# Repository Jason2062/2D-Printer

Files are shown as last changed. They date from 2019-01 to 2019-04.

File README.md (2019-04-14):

# 2D-Printer
This project is a realtime writing machine, which enable user to write information remotely. This design controls the movement of the pen on the x and y axes through two stepping motors and the up and down movement of the pen through a servo motor. The [Wiki page](https://github.com/Jason2062/2D-Printer/wiki) details how to recreate the machine.<br>

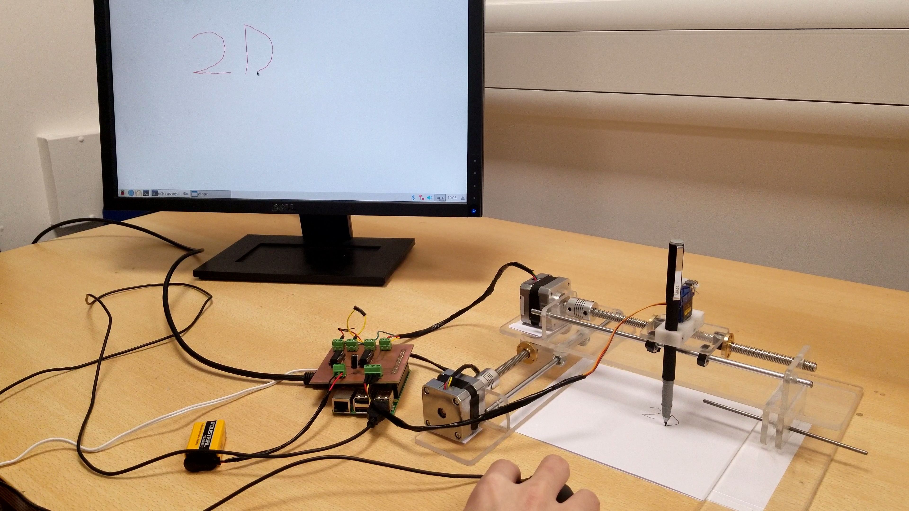
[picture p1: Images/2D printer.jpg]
2d printer


 # Software Design
 
# Flow Chart

The program is triggered by mouse clicks and movements. When the user moving the mouse, according to the comparison results of the x and y axis coordinates with their previous values, different threads are triggered to control the stepper motor rotating clockwise or anticlockwise and realize the x and y axis movement control of the pen. When the mouse is clicked, the Raspberry Pi switch the servo motor state to realize the pen point moving up and down. Besides, the GUI porvides the path record to facilitate the user to see the pattern printed by the 2D printer. 

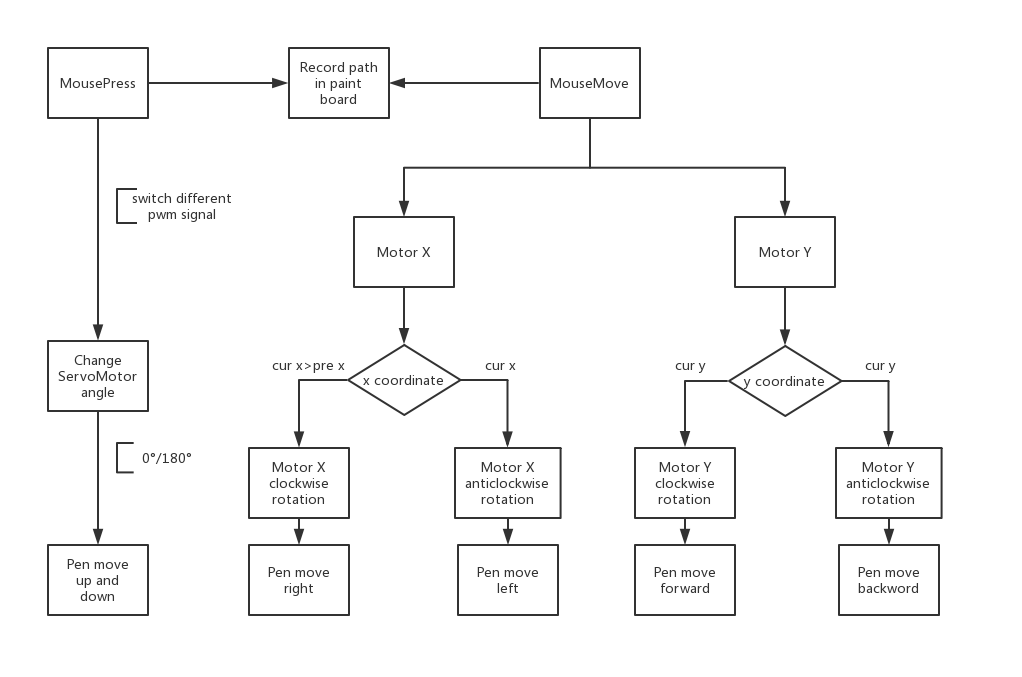
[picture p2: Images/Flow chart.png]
flow chart


# Required Package
## How to install QT5 and QT Creator
```
sudo apt-get update
sudo apt-get upgrade 

//Install QT5 

sudo apt-get install qt5-default

//Install QT creator

sudo apt-get install qtcreator
```
## How to install wiringPi

```
git clone git://git.drogon.net/wiringPi

cd wiringPi
./build

Type "gpio -v" to test

Type "gpio readall" to check pin information
```

# Documentation

[Doxygen documentation](http://htmlpreview.github.io/?https://github.com/Jason2062/2D-Printer/blob/master/Doxygen/html/annotated.html)

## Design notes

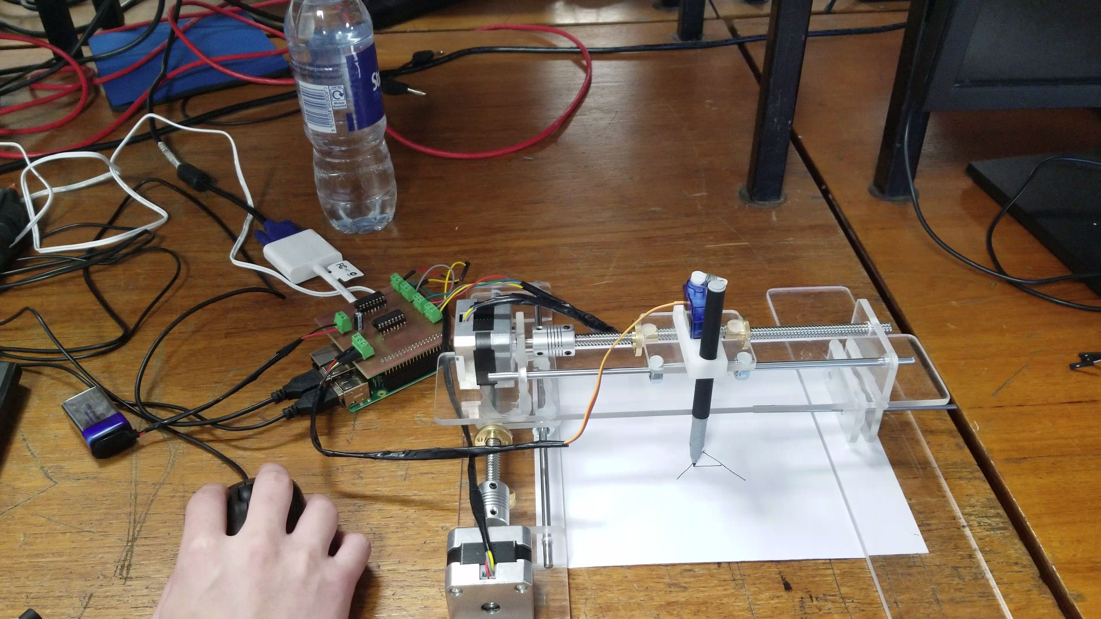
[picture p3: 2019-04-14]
Images/whole view.jpg

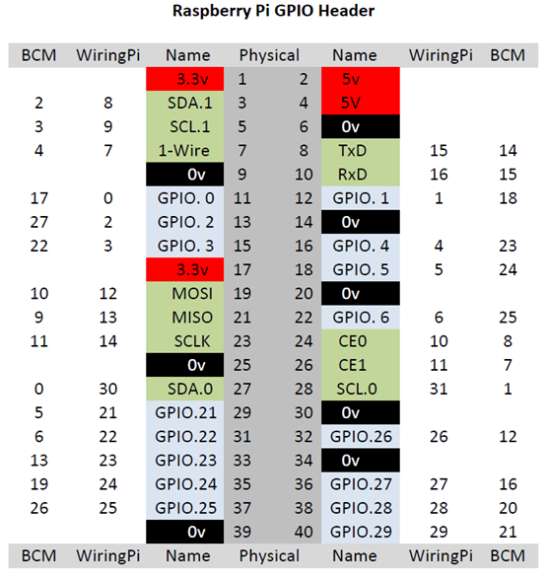
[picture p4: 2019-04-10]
Images/Raspberry Pi GPIO Header.png

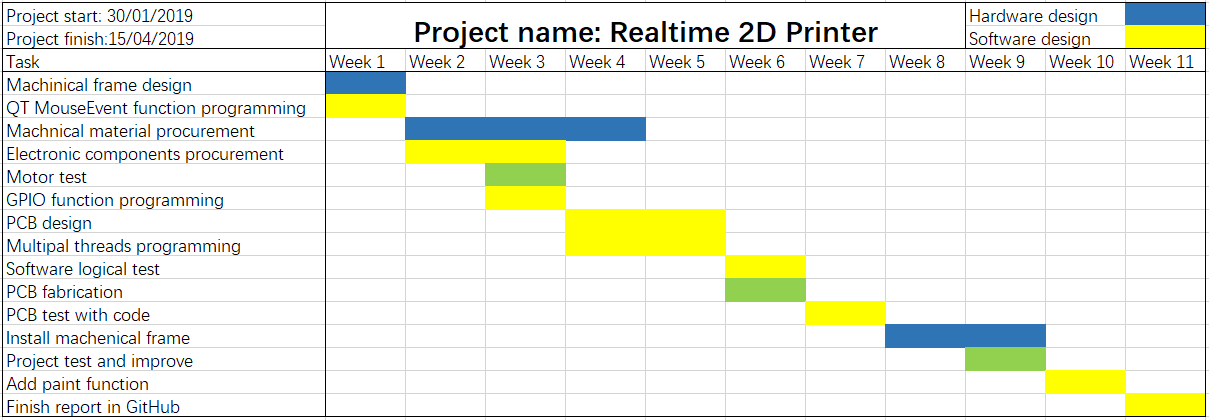
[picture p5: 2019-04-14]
Images/Gantt Chart.png

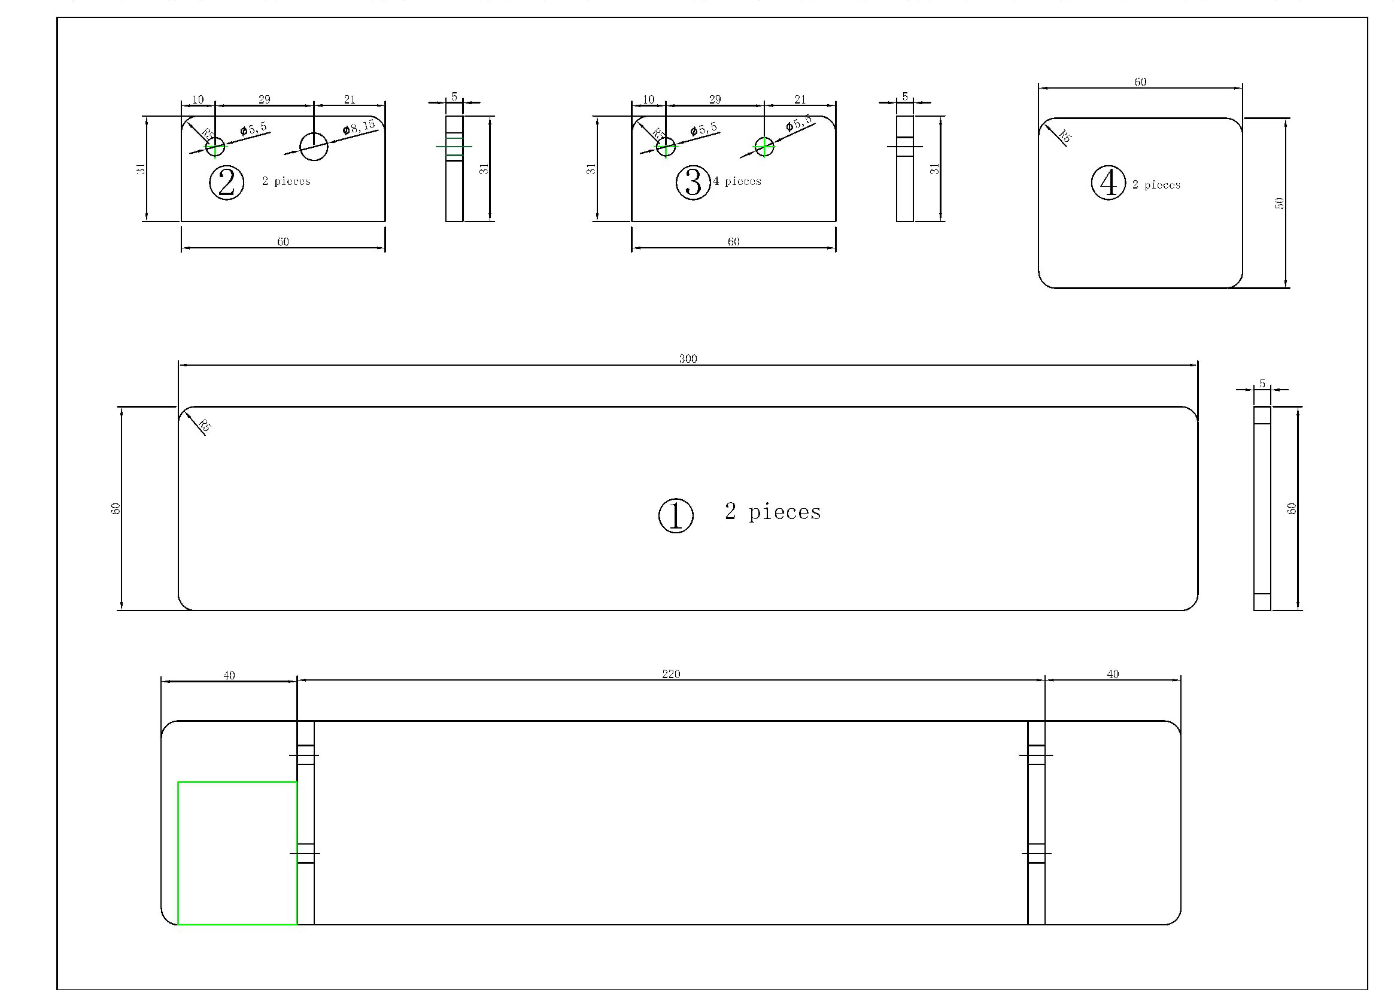
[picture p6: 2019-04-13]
Images/acrylic board.jpg

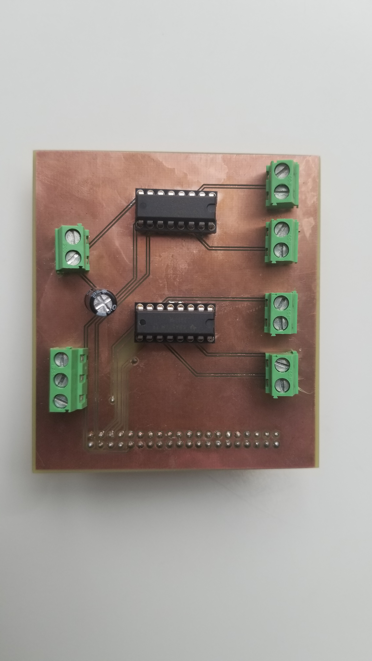
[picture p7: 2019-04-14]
Images/PCB.jpg

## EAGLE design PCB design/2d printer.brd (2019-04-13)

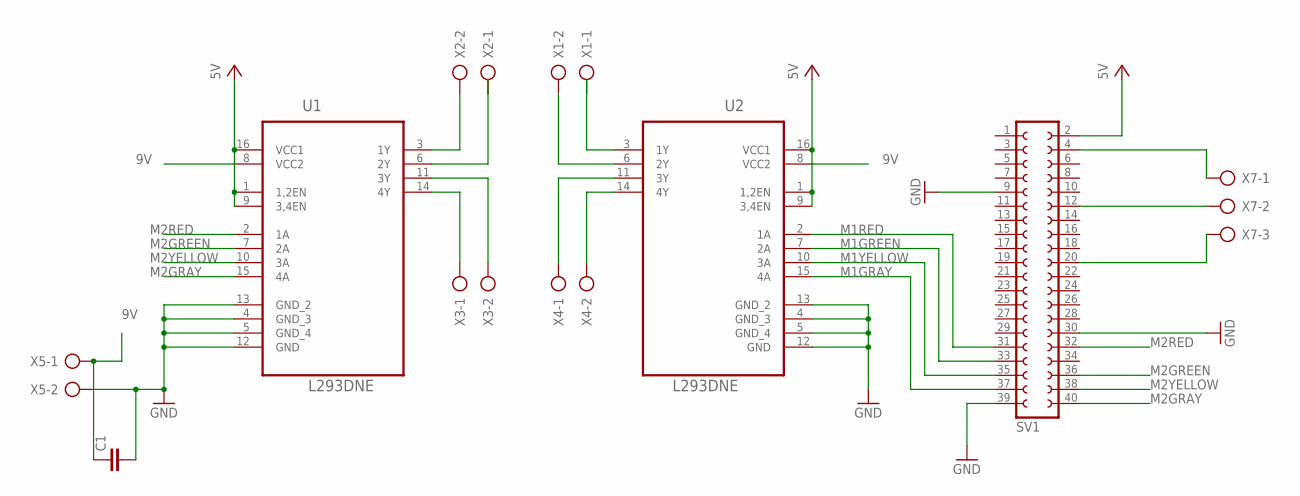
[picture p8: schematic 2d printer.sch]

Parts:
C1: C2.5/2; C2.5-2
SV1: FE20-2
U1, U2: L293DNE; DIP254P762X508-16
X1, X2, X3, X4, X5: AK300/2
X7: AK300/3

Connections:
9V: C1.1, U1.8 (VCC2), U2.8 (VCC2), X5.1
GND: C1.2, SV1.9, SV1.30, SV1.39, U1.4 (GND_3), U1.5 (GND_4), U1.12 (GND), U1.13 (GND_2), U2.4 (GND_3), U2.5 (GND_4), U2.12 (GND), U2.13 (GND_2), X5.2
M1GRAY: SV1.37, U2.15 (4A)
M1GREEN: SV1.33, U2.7 (2A)
M1RED: SV1.31, U2.2 (1A)
M1YELLOW: SV1.35, U2.10 (3A)
M2GRAY: SV1.40, U1.15 (4A)
M2GREEN: SV1.36, U1.7 (2A)
M2RED: SV1.32, U1.2 (1A)
M2YELLOW: SV1.38, U1.10 (3A)
unnamed: U2.3 (1Y), X1.1
unnamed: U1.3 (1Y), X2.2
unnamed: U1.6 (2Y), X2.1
unnamed: U1.14 (4Y), X3.1
unnamed: U1.11 (3Y), X3.2
unnamed: U2.14 (4Y), X4.2
unnamed: U2.6 (2Y), X1.2
unnamed: U2.11 (3Y), X4.1
unnamed: SV1.4, X7.1
unnamed: SV1.20, X7.3
unnamed: SV1.12, X7.2
VCC: SV1.2, U1.1 (1,2EN), U1.9 (3,4EN), U1.16 (VCC1), U2.1 (1,2EN), U2.9 (3,4EN), U2.16 (VCC1)

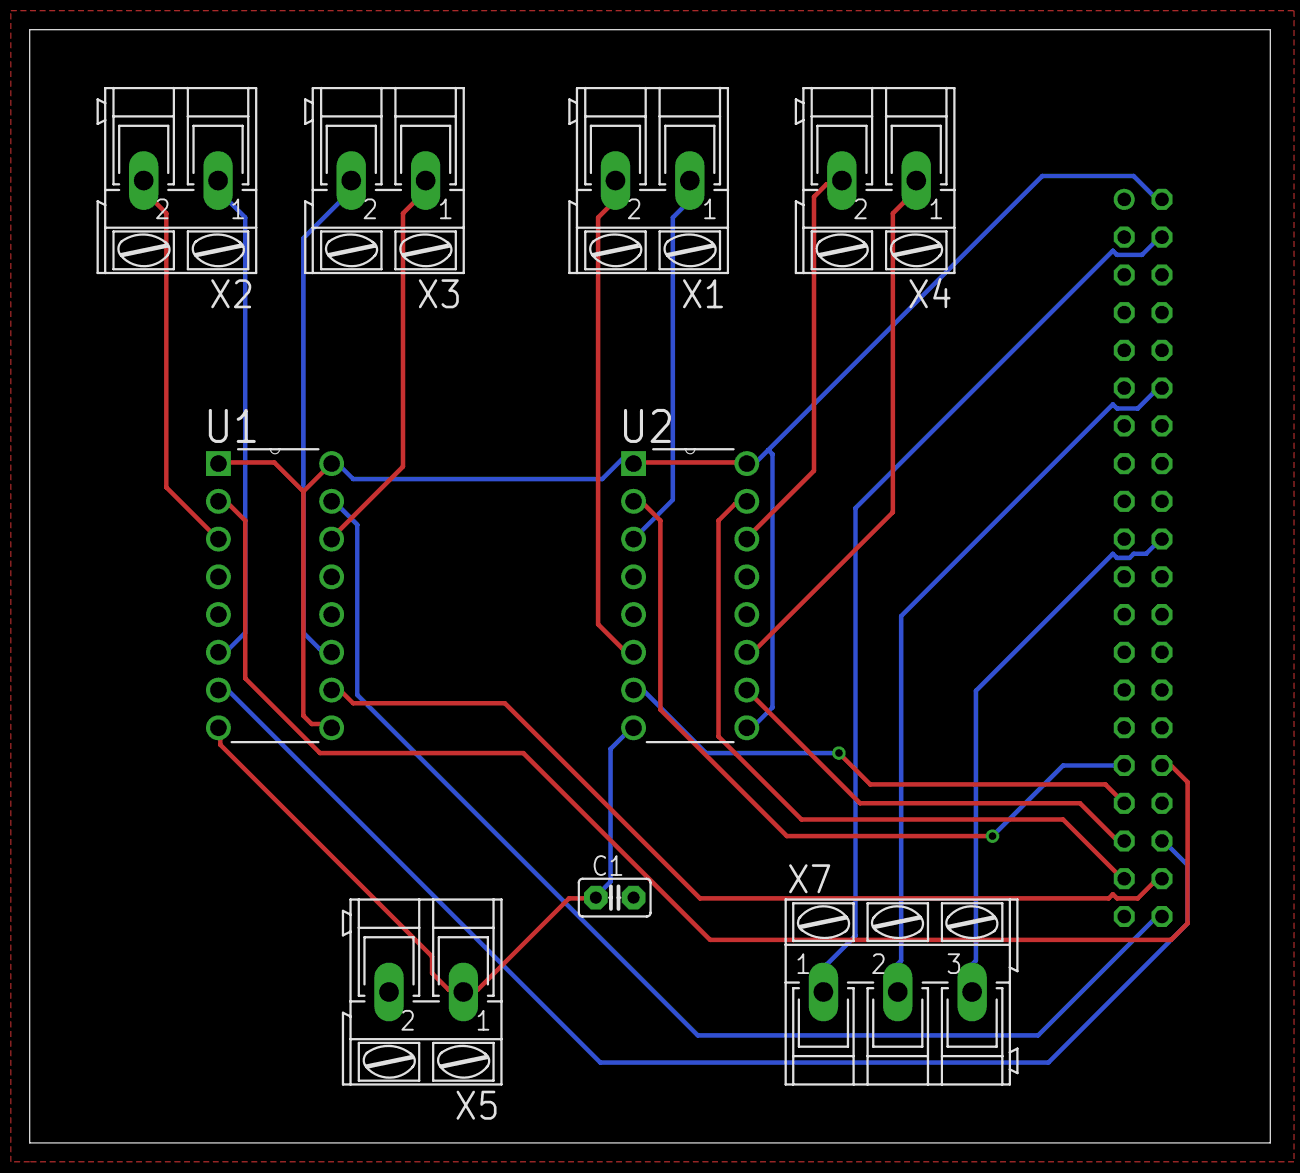
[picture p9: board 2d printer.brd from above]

Board: 2 copper layers, 83.5 x 74.9 mm, 10 parts (1 on the bottom side), 22 nets.

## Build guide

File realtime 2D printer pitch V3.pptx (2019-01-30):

## Realtime 2D Printer

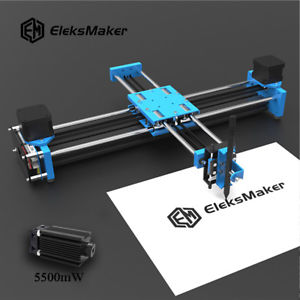
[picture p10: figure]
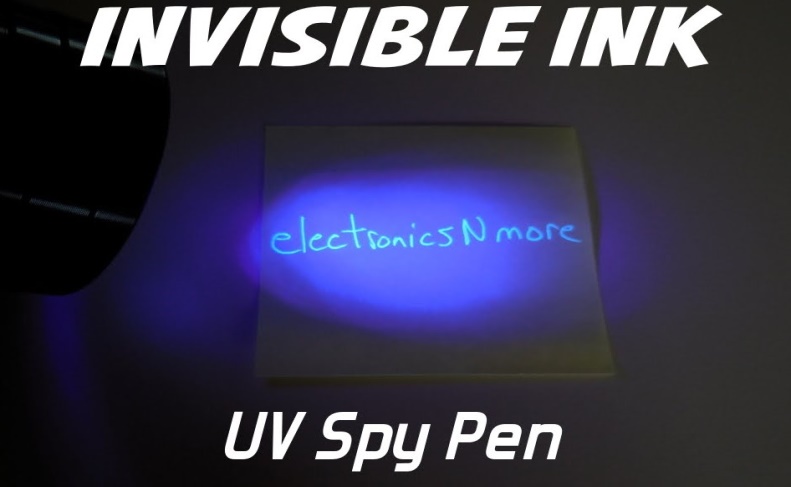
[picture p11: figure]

- Print out invisible message in the case of emergency
- Offer assist in the creation of complex UV paintings
- In the future applications the printer can achieve more purposes by replacing UV pen with other tools

Wei Zhang
Honghao Wang
Huanyu Zhang

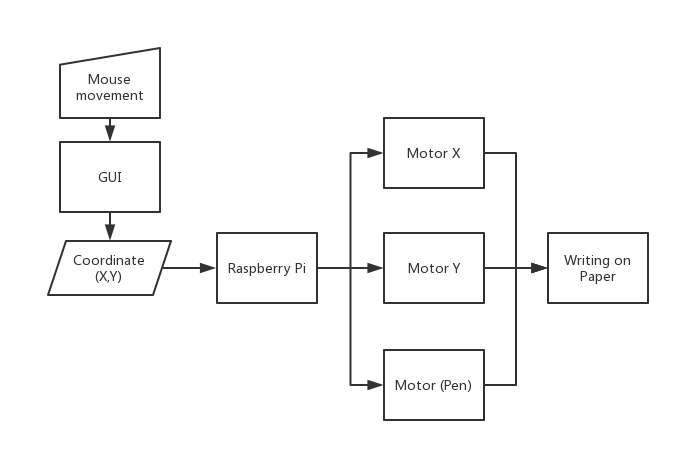
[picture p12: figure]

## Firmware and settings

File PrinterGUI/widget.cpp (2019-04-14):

#include "widget.h"
#include "ui_widget.h"
#include <QMouseEvent>
#include <QDebug>
#include <QPainter>
#include "qtglobal.h"

#include "xaxisr.h"
#include "xaxisl.h"

#include "yaxisr.h"
#include "yaxisl.h"

#include "wiringPi.h"
#include "softPwm.h"
/**
 * @brief Widget::Widget
 * @param parent
 */
Widget::Widget(QWidget *parent) :
    QWidget(parent),
    ui(new Ui::Widget)
{
    //create motor Threads
    xThreadr = new xAxisR(); //!< turn right xmotor threads
    xThreadl = new xAxisL(); //!< turn left  xmotor threads

    yThreadr = new yAxisR(); //!< turn right ymotor threads
    yThreadl = new yAxisL(); //!M turn left  ymotor threads

    //set painter

    //set backcolor=white
    QColor backcolor =qRgb(255,255,255);//!<set the color of paint board.
    //set the size of paint board
    m_image =QImage(2000,2000,QImage::Format_RGB32);//!< set the size of paint board.
    //fill the white board
    m_image.fill(backcolor);

    ui->setupUi(this);
    //display coordinates of mouse
    ui->estadoLineEdit->setReadOnly(true);
    ui->xPosSpinBox->setReadOnly(true);
    ui->yPosSpinBox->setReadOnly(true);

    ui->xPosSpinBox->setValue(cursor().pos().x());
    ui->yPosSpinBox->setValue(cursor().pos().y());
    //set the range of coordinates
    configureSpinBox(ui->xPosSpinBox, 0, +INT_MAX);//!< configure the display range of spinBox
    configureSpinBox(ui->yPosSpinBox, 0, +INT_MAX);//!< configure the display range of spinBox
    qDebug()<<"Hello"<<123;

    //set pinMode which controls the stepper motor rotation and servo motor.
    /**
     * @brief wiringPiSetup set pinMode which controls the stepper motor ration and servo motor.
     */
    wiringPiSetup();
    //stepper motor on x axis
    pinMode(22,OUTPUT);
    pinMode(23,OUTPUT);
    pinMode(24,OUTPUT);
    pinMode(25,OUTPUT);
    //stepper motor on y axis
    pinMode(26,OUTPUT);
    pinMode(27,OUTPUT);
    pinMode(28,OUTPUT);
    pinMode(29,OUTPUT);
    //servo motor pinMode
    pinMode(1,OUTPUT);
    softPwmCreate(1,0,100);
}

Widget::~Widget()
{
    delete ui;
}



/**
 * @brief Widget::mousePressEvent Create a mousePressEvent function. In this function, the servoState(pen) movement can be switched by mousePress event.
 * @param event
 */
void Widget::mousePressEvent(QMouseEvent *event)
{
    //painter: when mousePress happen, record the fisrt coordinate. mousePress always happens before mouseMove
    m_prevPoint = event->pos();

    //Control the up and down movement of the pen by give different PWM signal to pin 1.
    //Two different PWM period, 1ms and 2ms can be switched by mousePress

    if(qtGlobal::servoState==true)
    {
        //generate 2ms PWM period. When the on-time is 2ms the motor will be in 180°.
        softPwmWrite(1,20);
        qDebug()<<"20";
        //change the state of servoState, s
        qtGlobal::servoState=false;
    }
    else if(qtGlobal::servoState==false)
    {
        //generate 1ms PWM period. When the on-time is 1ms the motor will be in 0°.
        softPwmWrite(1,10);
        qDebug()<<"10";
        qtGlobal::servoState=true;
    }


    onMouseEvent("Press", event->pos());

    QWidget::mousePressEvent(event);

}
/**
 * @brief Widget::mouseMoveEvent define a mouseMoveEvent function. In this function, the path of mouseMove can be recorded by painter when the state of servomotor is true.
 * @param event
 */
void Widget::mouseMoveEvent(QMouseEvent *event)
{
    //when mouseMove happens, record the second coordinates. and connected with the first coordinate by painter.

    m_curPoint=event->pos();

    QPainter painter(&m_image);
    QPen pen;
    pen.setColor(Qt::red);
    pen.setWidth(2);
    painter.setPen(pen);

    //when servoState is true which means the pen is writing. The line will be connected.
    if(qtGlobal::servoState==true)
    {
        painter.drawLine(m_prevPoint,m_curPoint);
    }
    update();
    m_prevPoint = m_curPoint;


    //onMouseEvent

    onMouseEvent("Move", event->pos());

    QWidget::mouseMoveEvent(event);
}

/**
 * @brief Widget::configureSpinBox In this function, the display range can be set.
 * @param spinBox name of spinBox
 * @param min min number
 * @param max max number
 */
void Widget::configureSpinBox(QSpinBox *spinBox, int min, int max) const
{
    spinBox->setMinimum(min);
    spinBox->setMaximum(max);
}
/**
 * @brief Widget::onMouseEvent In this function, the coordinate of mouse will be recorded and compared with previous number when mouseMoveEvent and mousePressEvent happens.
 * @param eventName
 * @param pos
 */
void Widget::onMouseEvent(const QString &eventName, const QPoint &pos)
{
    //display the event of mouse
    ui->estadoLineEdit->setText(eventName);

    //
    qDebug()<<qtGlobal::xValue;
    qDebug()<<pos.x();

    //if the current x value larger than the previous value. The xThreadr thread start.
    if(pos.x()>qtGlobal::xValue)
    {
        xThreadr->start();
    }
    //if the current x value smaller than the previous value. The xThreadl thread start.
    else if(pos.x()<qtGlobal::xValue)
    {
        xThreadl->start();
    }
    //if the current y value larger than the previous value. The xThreadr thread start.
    if(pos.y()>qtGlobal::yValue)
   {
       yThreadr->start();
    }
    //if the current y value smaller than the previous value. The xThreadl thread start.
    else if (pos.y()<qtGlobal::yValue)
    {
        yThreadl->start();
    }
    //assign the current coordinate to xValue and yValue.
    qtGlobal::xValue=pos.x();
    qtGlobal::yValue=pos.y();
    ui->xPosSpinBox->setValue(pos.x());
    ui->yPosSpinBox->setValue(pos.y());
}
/**
 * @brief Widget::paintEvent draw image of mousepath
 */
void Widget::paintEvent(QPaintEvent *)
{
    QPainter painter(this);
    painter.drawImage(0,0,m_image);
}
/**
 * @brief Widget::on_pushButton_clicked In this function, the paint board will be reset once the refresh button is clicked.
 */
void Widget::on_pushButton_clicked()
{
    //When press click refresh button, reset backboard.
    QColor backcolor=qRgb(255,255,255);
    m_image=QImage(2000,2000,QImage::Format_RGB32);
    m_image.fill(backcolor);
    update();
}

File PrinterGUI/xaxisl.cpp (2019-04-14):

#include "xaxisl.h"

#include "wiringPi.h"
#include <QDebug>

xAxisL::xAxisL()
{

}

//turn left by 7.2°.
/**
 * @brief xAxisL::run run threads which turn left the x Motor by 7.2°.
 */
void xAxisL::run()
{

    digitalWrite(22,HIGH);
    digitalWrite(23,LOW);
    digitalWrite(24,LOW);
    digitalWrite(25,LOW);
    delay(10);
    digitalWrite(22,LOW);
    digitalWrite(23,HIGH);
    digitalWrite(24,LOW);
    digitalWrite(25,LOW);
    delay(10);
    digitalWrite(22,LOW);
    digitalWrite(23,LOW);
    digitalWrite(24,HIGH);
    digitalWrite(25,LOW);
    delay(10);
    digitalWrite(22,LOW);
    digitalWrite(23,LOW);
    digitalWrite(24,LOW);
    digitalWrite(25,HIGH);
    delay(10);

}

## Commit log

2019-04-13 Create PrinterGUI
2019-04-14 Add files via upload
    PCB
